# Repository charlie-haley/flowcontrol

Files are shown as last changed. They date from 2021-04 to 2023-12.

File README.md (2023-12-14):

> **Due to not having to the time to work on this, this project will be archived. It may return in another form in the future.**
>
<p align="center" style="text-align: center">
   <a href="https://flowctl.app">
      <br/>
   </a>
   An open source, multiplatform fan controller.
</p>

**This project is still in a very early state. If you'd like to contribute, [please take a look at our outstanding issues](https://github.com/charlie-haley/flowcontrol/issues) and raise a PR** 
Alternatively, head over to [discussions](https://github.com/charlie-haley/flowcontrol/discussions) if you have any questions or ideas.




<p align="center" style="text-align: center">
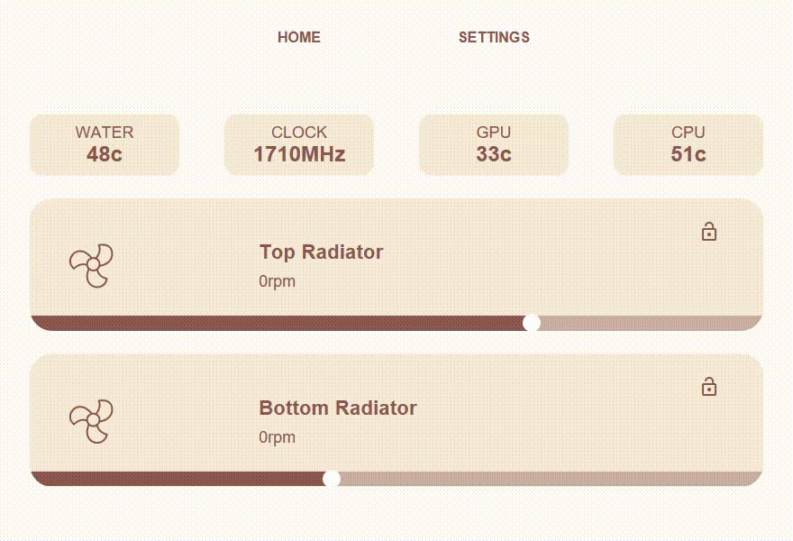
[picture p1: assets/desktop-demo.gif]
   <br/>
</p>

## 📝 Getting Started

[Head over to the documentation to get started.](https://flowctl.app/getting-started/requirements/)

## ❓ FAQ

- **What is this?**<br/>
A fan controller with open-source hardware, software and a CLI.

- **Who's it for?**<br/>
It's primarily aimed at desktop computer users, but it can fit many use cases.

- **How can I use flowcontrol?**<br/>
At the moment, you will need the ability to solder so you can build the hardware, if it proves popular I may release some pre-built controllers. [You can find the documentation on building the controller here.](https://flowctl.app/getting-started/requirements/)

- **Why would I use this over X?**<br/>
This started out as a project for me to use personally, I was tired of expensive fan controllers with proprietary connectors and no Linux support.

## Special Thanks

Huge thank you to all the awesome open source projects that have made this possible!
- [Wails](https://github.com/wailsapp/wails)
- [Cobra](https://github.com/spf13/cobra)
- [Raspberry Pi Pico](https://www.raspberrypi.org/products/raspberry-pi-pico/)
- [YoungSerif](https://github.com/noirblancrouge/YoungSerif)
- [KiCad](https://www.kicad.org/)
- [Gridsome](https://github.com/gridsome/gridsome)

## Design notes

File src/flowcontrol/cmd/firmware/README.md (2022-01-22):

# firmware

The firmware has been written around a [rp2040 microcontroller](https://www.raspberrypi.org/documentation/rp2040/getting-started/), prototypes have been built using the [Raspberry Pi Pico](https://www.raspberrypi.org/products/raspberry-pi-pico/)

## Compiling with tinygo
```
tinygo build -o=$(pwd)/main.uf2 -target=pico main.go
```

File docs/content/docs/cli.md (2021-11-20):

---
description: ''
sidebar: 'docs'
---

## CLI
A CLI application built using [cobra](https://github.com/spf13/cobra)

## Prerequisites
- Go 1.12+

## Running Locally
```
cd src/flowcontrol-cli/
go install flowctl
```

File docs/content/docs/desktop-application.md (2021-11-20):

---
description: ''
sidebar: 'docs'
---

## Desktop Application
This is the GUI application. It's built using [wails](https://wails.app/)

## Prerequisites
- Go 1.12+
- npm
- net5 SDK (Optional, only required if you're using the monitor)

### Linux
- gcc, gtk, webkitgtk

## Running locally

### flowcontrol
```
cd src/flowcontrol/
wails serve

cd src/flowcontrol/frontend
npm run serve
```

### flowcontrol-monitor
This is the supplementary application to the main one. It provides system metrics such as GPU Clock and temperatures using [LibreHardwareMonitorLib](https://github.com/LibreHardwareMonitor/LibreHardwareMonitor). I'm aiming to make this an optional component for people who want hardware metrics beyond the scope of the controller, it's currently bundled with the release.
```
cd src/flowcontrol-monitor/
dotnet run
```

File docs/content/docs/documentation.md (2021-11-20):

---
description: ''
sidebar: 'docs'
---

## Documentation
## Prerequisites

- Gridsome CLI

## Running Locally
```
cd src/flowcontrol/docs
gridsome develop
```

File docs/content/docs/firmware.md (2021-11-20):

---
description: ''
sidebar: 'docs'
---

## Firmware

## Prerequisites

- Micro USB Cable

Flash firmware to the RPI Pico using your favourite IDE (VSCode, Thonny)

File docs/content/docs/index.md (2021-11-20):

---
description: ''
sidebar: 'docs'
next: '/docs/pcb/'
---

# Introduction

Existing consumer fan controllers can be expensive, contain properietry connectors and the software that ships with them is usually incompatible with any operating system aside from Windows.

The aim of this project is make an accessible and extensible fan controller that is built for the user.

## Features
- Cheap, open source hardware built on top of the readily available Raspberry Pi Pico
- Lightweight desktop app
- Command line interface
- Support for external temp sensors
- User configurable fan curves (coming soon!)
- DRGB strip support (coming soon!)

## Parts List
__!! Note: If you can solder SMD components, there's a PCB available. [Please refer to the PCB documentation for the relevant parts list](/docs/pcb). !!__

Here's a list of parts you'll need if you'd like to build the hardware yourself:

- USB to UART module
- [Raspberry Pi Pico](https://www.raspberrypi.org/products/raspberry-pi-pico/)
- x2 Female and Male JST Connectors (For temp sensors, optional)
- 1 of each, per fan:
  - 4-Pin PWM Fan Connector Male
  - 10k Resistors

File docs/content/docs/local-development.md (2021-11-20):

---
description: ''
sidebar: 'docs'
---

# Local Development

The code base consists:

  - [flowcontrol](#desktop-application)
  - [flowcontrol-monitor](#desktop-application)
  - [flowcontrol-cli](#cli)
  - [firmware](#firmware)
  - [documentation](#documentation)

`flowcontrol` and `flowcontrol-cli` are currently independent, I'm looking to consolidate their codebase now they're both using Go and utilise shared packages for stuff like serial communication.

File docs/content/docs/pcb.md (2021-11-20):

---
description: ''
sidebar: 'docs'
prev: '/docs/'
next: '/docs/writing-content/'
---

# PCB

## Layout



## Bill Of Materials

Here's a list of parts with the corresponding designator on the PCB and the footprint.

| Designator | Comment | Footprint |
|:---:|:---:|:---:|
| C1 | 10uF | C_0603_1608Metric |
| C2, C3, C6 | 100nF | C_0603_1608Metric |
| C4, C5 | 22pF | C_0603_1608Metric |
| D1, D2 | LL4148 | D_SMA |
| D3, D4, D5 | LED | D_SMA |
| R1, R2, R3, R4  | 10k Ω | R_0603_1608Metric |
| R5, R6, R7, R8  | 1k5 | R_0603_1608Metric |
| SW1 | K2-1102SP-C4SC-04 | SW_Push_1P1T_NO_6x6mm_H9.5mm |
| U1 | 12MHz Crystal | RPI Pico |
| U2 | CH340G | SOIC-16_3.9x9.9mm_P1.27mm |
| Y1 | 12MHz Crystal | Crystal_SMD_HC49-SD |
| J1, J2 | 4 Pin PWM Fan Connector | Right Angle |
| J3, J4 | 2 Pin JST XH | 2 Pin JST XH |
| J5 | 2x05 2.54mm Female Header  | 2x05 2.54mm Female Header |
| J6 | MATE-N-LOK 350211-1 | (4 Pin "Molex" Connector) |
| J7 | 1x04 2.54mm Male Header | 1x04 2.54mm Male Header |

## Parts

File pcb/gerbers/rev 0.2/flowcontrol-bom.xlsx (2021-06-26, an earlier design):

Comment | Designator | Footprint | LCSC Part #（optional）
10uF | C1 | C_0603_1608Metric
100nF | C2 | C_0603_1608Metric
100nF | C3 | C_0603_1608Metric
22pF | C4 | C_0603_1608Metric
22pF | C5 | C_0603_1608Metric
100nF | C6 | C_0603_1608Metric
LL4148 | D1 | D_SMA
LL4148 | D2 | D_SMA
LED | D3 | D_SMA
LED | D4 | D_SMA
LED | D5 | D_SMA
10k Ω | R1 | R_0603_1608Metric
10k Ω | R2 | R_0603_1608Metric
10k Ω | R3 | R_0603_1608Metric
10k Ω | R4 | R_0603_1608Metric
1k5 | R5 | R_0603_1608Metric
1k5 | R6 | R_0603_1608Metric
1k5 | R7 | R_0603_1608Metric
1k5 | R8 | R_0603_1608Metric
K2-1102SP-C4SC-04 | SW1 | SW_Push_1P1T_NO_6x6mm_H9.5mm
CH340G | U2 | SOIC-16_3.9x9.9mm_P1.27mm
12MHz Crystal | Y1 | Crystal_SMD_HC49-SD

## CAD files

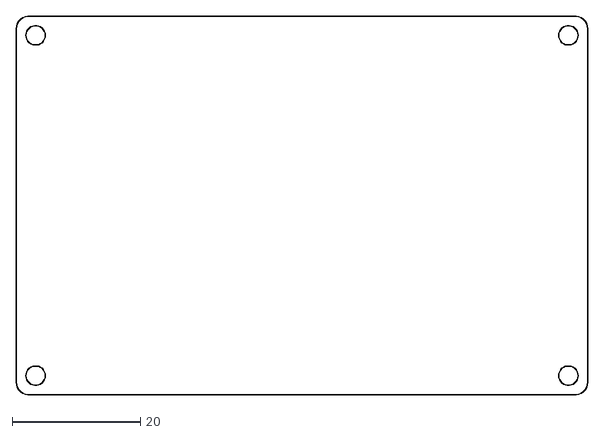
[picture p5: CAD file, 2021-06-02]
pcb/src/outline.dxf
89.0 x 59.0

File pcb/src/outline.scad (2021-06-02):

difference(){  
    minkowski()
    {
        square([85, 55], center = true);
        circle(r=2, $fn=30);
    }
    translate([41.5,26.5]) circle(d=3.01, $fn=30);
    translate([-41.5,26.5]) circle(d=3.01, $fn=30);
    translate([41.5,-26.5]) circle(d=3.01, $fn=30);
    translate([-41.5,-26.5]) circle(d=3.01, $fn=30);
}

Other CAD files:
assets/flowcontrol-logo.dxf

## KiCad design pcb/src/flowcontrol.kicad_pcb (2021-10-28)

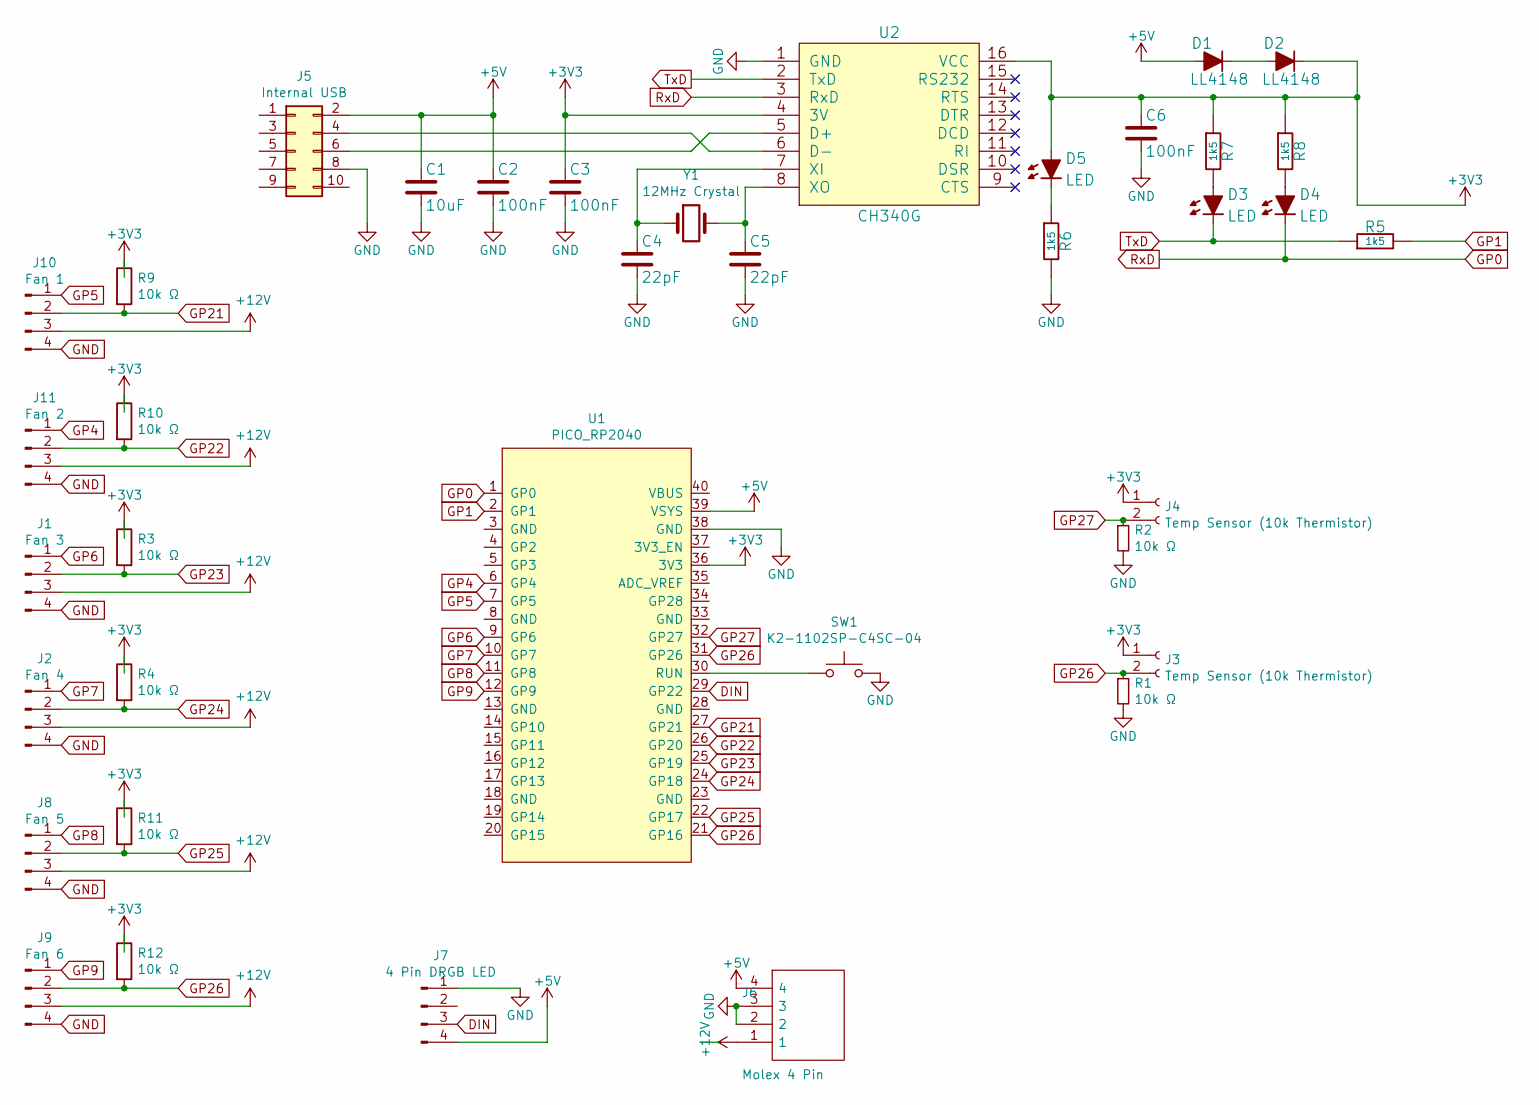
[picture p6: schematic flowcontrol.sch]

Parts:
C1: 10uF; C_0603_1608Metric
C2, C3, C6: 100nF; C_0603_1608Metric
C4, C5: 22pF; C_0603_1608Metric
D1, D2: LL4148; D_SMA
D3, D4, D5: LED; D_SMA
J1: Fan 3; PinHeader_1x04_P2.54mm_Horizontal
J2: Fan 4; PinHeader_1x04_P2.54mm_Horizontal
J3, J4: Temp Sensor (10k Thermistor); JST_XH_S2B-XH-A-1_1x02_P2.50mm_Horizontal
J5: Internal USB; PinSocket_2x05_P2.54mm_Horizontal
J6: Molex 4 Pin; 641737-1
J7: 4 Pin DRGB LED; PinHeader_1x04_P2.54mm_Horizontal
J8: Fan 5; PinHeader_1x04_P2.54mm_Horizontal
J9: Fan 6; PinHeader_1x04_P2.54mm_Horizontal
J10: Fan 1; PinHeader_1x04_P2.54mm_Horizontal
J11: Fan 2; PinHeader_1x04_P2.54mm_Horizontal
R1, R2, R3, R4, R9, R10, R11, R12: 10k Ω; R_0603_1608Metric
R5, R6, R7, R8: 1k5; R_0603_1608Metric
SW1: K2-1102SP-C4SC-04; SW_Push_1P1T_NO_6x6mm_H9.5mm
U1: PICO_RP2040; RPi_Pico_SMD_TH
U2: CH340G; SOIC-16_3.9x9.9mm_P1.27mm
Y1: 12MHz Crystal; Crystal_SMD_HC49-SD

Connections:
+3V3: C3.1, C6.1, D2.1 (A), D5.2 (C), J3.1, J4.1, R3.1, R4.1, R7.1, R8.1, R9.1, R10.1, R11.1, R12.1, U1.36 (3V3), U2.4 (3V), U2.16 (VCC)
+5V: C1.1, C2.1, D1.2 (C), J5.2, J6.4, J7.4, U1.39 (VSYS)
+12V: J1.3, J2.3, J6.1, J8.3, J9.3, J10.3, J11.3
DIN: J7.3, U1.29 (GP22)
GND: C1.2, C2.2, C3.2, C4.2, C5.2, C6.2, J1.4, J2.4, J5.8, J6.2, J6.3, J7.1, J8.4, J9.4, J10.4, J11.4, R1.2, R2.2, R6.2, SW1.2, U1.38 (GND), U2.1 (GND)
GP0: D4.1 (A), U1.1 (GP0), U2.3 (RxD)
GP1: R5.2, U1.2 (GP1)
GP4: J11.1, U1.6 (GP4)
GP5: J10.1, U1.7 (GP5)
GP6: J1.1, U1.9 (GP6)
GP7: J2.1, U1.10 (GP7)
GP8: J8.1, U1.11 (GP8)
GP9: J9.1, U1.12 (GP9)
GP21: J10.2, R9.2, U1.27 (GP21)
GP22: J11.2, R10.2, U1.26 (GP20)
GP23: J1.2, R3.2, U1.25 (GP19)
GP24: J2.2, R4.2, U1.24 (GP18)
GP25: J8.2, R11.2, U1.22 (GP17)
GP26: J3.2, J9.2, R1.1, R12.2, U1.21 (GP16), U1.31 (GP26)
GP27: J4.2, R2.1, U1.32 (GP27)
unnamed: C4.1, U2.7 (XI), Y1.1
unnamed: C5.1, U2.8 (XO), Y1.2
unnamed: D1.1 (A), D2.2 (C)
unnamed: D3.2 (C), R7.2
unnamed: D4.2 (C), R8.2
unnamed: D5.1 (A), R6.1
unnamed: J5.4, U2.6 (D-)
unnamed: J5.6, U2.5 (D+)
unnamed: SW1.1, U1.30 (RUN)
TxD: D3.1 (A), R5.1, U2.2 (TxD)

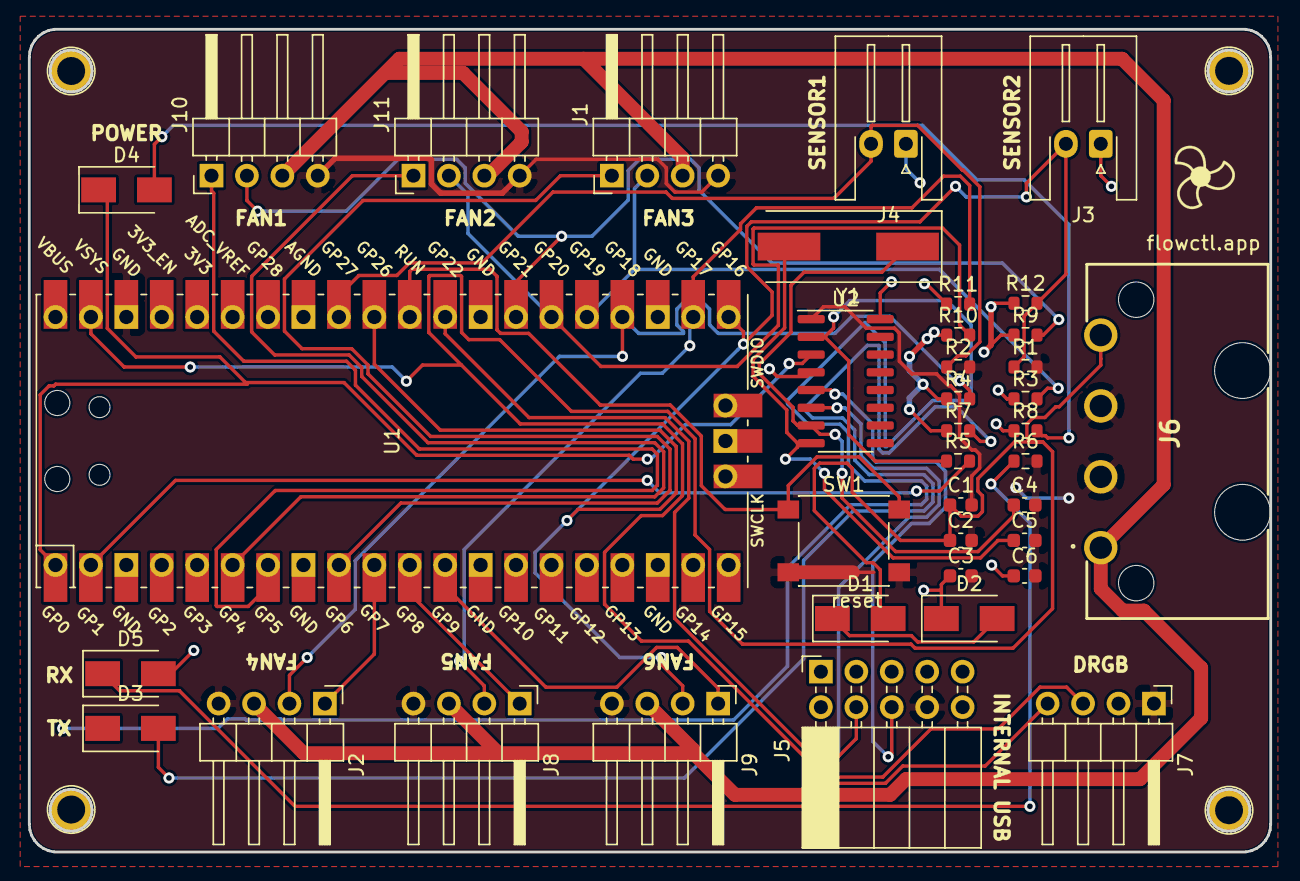
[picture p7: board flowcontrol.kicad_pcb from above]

Board: 2 copper layers, 89.0 x 59.0 mm, 38 parts (0 on the bottom side), 30 nets.

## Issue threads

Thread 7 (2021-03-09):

Add Neopixels LED support

charlie-haley, 2021-03-09:
add support for Neopixels DRGB

charlie-haley, 2021-04-11:
resolved by https://github.com/charlie-haley/flowcontrol/pull/18

Closed 2021-04-11.

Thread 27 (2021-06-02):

PCB Improvements

charlie-haley, 2021-06-02:
- [x] - Fix orientation of right angle fan headers (current solution is use to vertical mounting ones and follow schematic for pin placement)
- [x] - Add reset button so the Pico can be reset without removing the molex
- [x] - Design CH340g circuit and have it presoldered on the PCB as an alternative to using a USB-TTY dongle
- [x] Thicker traces to avoid damaging the PCB as easily

charlie-haley, 2021-06-26:
PCB in production, files in #39

Closed 2021-06-26.

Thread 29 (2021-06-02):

2 clicks needed to register an event

charlie-haley, 2021-06-02:
ex. changing the fans auto state using the padlock symbol involves 2 clicks

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

the pico registers the following inputs
```
Received Input:XA0
Received Input:XA0
Received Input:XA1
Received Input:XA1
```

charlie-haley, 2021-06-02:
After a bit more investigation - it seems to be sending the previous serial input, it's pretty inconsistent.

charlie-haley, 2021-06-02:
serial console and CLI app exhibinting similar behaviour, issue possibly on firmware side of things

charlie-haley, 2021-08-23:
Unable to replicate this on the latest revision PCB + Firmware. Closing

Closed 2021-08-23.

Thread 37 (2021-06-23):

Serial IO randomly breaks

charlie-haley, 2021-06-23:
Investigate why serial IO stops working.

I've tried replacing the CH340g for a rs232, issue looks to be on the pico/micropython side of things

charlie-haley, 2021-11-28:
Haven't seen this issue since the latest hardware revisions - closing for now.

Closed 2021-11-28.

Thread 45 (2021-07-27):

TX/RX Issues with rev 2 PCB

charlie-haley, 2021-07-27:
Issues with reading writing over UART on the new PCB. CH340 is detected and the TX LED lights up when sending data down the serial port

charlie-haley, 2021-08-08:
Issue was due to TX/RX being the wrong way around in the schematic. This will be fixed in the rev 3 PCB

Closed 2021-08-08.

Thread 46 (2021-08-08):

"Molex" 4 Pin Connector wrong way around

charlie-haley, 2021-08-08:
Fixed in rev3 PCB, tracking here

Closed 2021-08-08.

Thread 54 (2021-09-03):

Assign friendly device identifier

charlie-haley, 2021-09-03:
Investigate if I can assign a friendly name to the USB device - instead of showing as "CH340G" show "Flowcontrol" as the device identifier

charlie-haley, 2022-01-10:
the CH341A and CH340B have onboard EEPROM, it may be possible to use one of those, it'll also make this https://github.com/charlie-haley/flowcontrol/issues/5 infinitely simpler (potential rev 5 PCB task)

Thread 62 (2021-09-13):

Move firmware to TinyGo

charlie-haley, 2021-09-13:
Currently can't move the firmware to TinyGo due to the rp2040 not having PWM support, this is being worked on. See: https://github.com/tinygo-org/tinygo/issues/1993

charlie-haley, 2021-10-01:
Now being worked on

Closed 2022-01-22.

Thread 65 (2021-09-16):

Create revision 4 PCB

charlie-haley, 2021-09-16:
- [x] Use 3.3v pull-up instead of 5v on the tach
- [x] Increase fan headers to 6 with 6 independent PWM channels
- [ ] Potentially add generic power connector so SATA or "Molex" 4-Pin can be used
- [x] Add right angle internal USB connector

charlie-haley, 2021-11-12:
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

final layout of PCB, sent off for fab.

Closed 2021-11-12.

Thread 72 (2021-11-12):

build gerber files as part of the pipeline

charlie-haley, 2021-11-12:
investigate if gerber files can be built as part of the pipeline

charlie-haley, 2021-12-11:
This should be possible with Python bindings shipped with Kicad https://github.com/KiCad/kicad-source-mirror/blob/master/demos/python_scripts_examples/gen_gerber_and_drill_files_board.py

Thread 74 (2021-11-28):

sensor 2 outputs similiar reading to sensor 1

charlie-haley, 2021-11-28:
Sensor 2 is outputting a similar reading to sensor 1, it also looks like when only 1 sensor is connected the reading is double what it should it be.

Needs further investigation.

_Note: I haven't had the chance to try different thermistors, so the double reading could be an issue there._

charlie-haley, 2021-12-10:
Tested with new thermistors, issue lies with the thermistor, not the firmware/hardware. Closing.

charlie-haley, 2021-12-10:
I was wrong, issue seems to still be present - it's also registering a value in sensor 2 with nothing connected, I'm leaning towards hardware issue

charlie-haley, 2022-01-10:
factoring in the resistance of both sensors when fetching the rth seems to work for now, will investigate further and re-open if it should be solved in the hardware

charlie-haley, 2022-01-22:
re-opening, the sensor reading is now accurate but, value is identical

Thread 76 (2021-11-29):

LEDS not functioning as expected on the PCB

charlie-haley, 2021-11-29:
LEDs are in the wrong positions on the rev 4 PCB

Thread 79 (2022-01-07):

investigate need for EEPROM

charlie-haley, 2022-01-07:
investigate need for EEPROM, or if the filesystem on the pico will suffice, should be possible with https://github.com/tinygo-org/tinyfs

things to test:
- [ ] persistence
- [ ] speed and reliability

charlie-haley, 2022-01-07:
after further investigation, I'm opting for EEPROM, will be added to the revision 5 PCB

Closed 2022-01-07.

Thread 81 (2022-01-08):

only echo state when there's a change

charlie-haley, 2022-01-08:
**What problem are you looking to solve**
Currently, the state echo has to be triggered on input over UART. Ideally a routine will run in the background, monitor the state of sensors and fans and echo a response only when they've been updated

**Additional context**
The desktop app polls the hardware to get a response to get around this, but it's not ideal

Closed 2022-01-22.

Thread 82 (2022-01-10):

firmware to detect connected fans

charlie-haley, 2022-01-10:
**What problem are you looking to solve**
The firmware will need to detect if a fan is connected, then report on it. This will most likely come with tach support as we can detect the RPM of the fan https://github.com/charlie-haley/flowcontrol/issues/6

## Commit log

2021-03-11 DNMY - Basic start to PCB/CLI updates (#11)
    * initial commit
    * initial commit
    * initial commit
    * modify port num to prevent clash with logitech
    * move to blazor, add hacky RGB support to nano
    * add missing files
    * tidy up messy firmware a bit
    * fix issue with auto mode
    * Add new firmware using rp2040
    * add cli, move folder structure
    * CLI in somewhat working state and firmware updates
    * Remove old firmware
    * add basic start to PCB/Cli updates
    * update PCB
    [flowcontrol-v0.1.kicad_pcb, flowcontrol-v0.1.sch]
2021-03-13 Improvements to Thermistor readings (#14)
    * improve handling of temp reading
    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
2021-04-04 Migrate away from Chromely, use Wails instead (#15)
    * Migrate away from Chromely, use Wails instead
    * add flowcontrol-monitor application
2021-04-06 Desktop app updates (#16)
    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
2021-05-09 Bump ssri from 6.0.1 to 6.0.2 in /src/flowcontrol/frontend (#21)
    Bumps [ssri](https://github.com/npm/ssri) from 6.0.1 to 6.0.2.
    - [Release notes](https://github.com/npm/ssri/releases)
    - [Changelog](https://github.com/npm/ssri/blob/v6.0.2/CHANGELOG.md)
    - [Commits](https://github.com/npm/ssri/compare/v6.0.1...v6.0.2)
2021-05-09 Bump hosted-git-info from 2.8.8 to 2.8.9 in /src/flowcontrol/frontend (#22)
    Bumps [hosted-git-info](https://github.com/npm/hosted-git-info) from 2.8.8 to 2.8.9.
    - [Release notes](https://github.com/npm/hosted-git-info/releases)
    - [Changelog](https://github.com/npm/hosted-git-info/blob/v2.8.9/CHANGELOG.md)
    - [Commits](https://github.com/npm/hosted-git-info/compare/v2.8.8...v2.8.9)
2021-06-02 add v0.1 PCB files and gerbers (#28)
    * add v0.1 PCB files and gerbers
    * add v0.1 PCB files and gerbers
    [flowcontrol-v0.1-B_Cu.gbr, flowcontrol-v0.1-B_Mask.gbr, flowcontrol-v0.1-B_Paste.gbr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]
2021-06-09 Bump dns-packet from 1.3.1 to 1.3.4 in /src/flowcontrol/frontend (#30)
    Bumps [dns-packet](https://github.com/mafintosh/dns-packet) from 1.3.1 to 1.3.4.
    - [Release notes](https://github.com/mafintosh/dns-packet/releases)
    - [Changelog](https://github.com/mafintosh/dns-packet/blob/master/CHANGELOG.md)
    - [Commits](https://github.com/mafintosh/dns-packet/compare/v1.3.1...v1.3.4)
    ---
    updated-dependencies:
    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
2021-06-10 Bump ws from 6.2.1 to 6.2.2 in /src/flowcontrol/frontend (#35)
    Bumps [ws](https://github.com/websockets/ws) from 6.2.1 to 6.2.2.
    - [Release notes](https://github.com/websockets/ws/releases)
    - [Commits](https://github.com/websockets/ws/compare/6.2.1...6.2.2)
    - dependency-name: ws
    dependency-type: indirect
    ...
    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
2021-06-10 Bump browserslist from 4.16.3 to 4.16.6 in /src/flowcontrol/frontend (#36)
    Bumps [browserslist](https://github.com/browserslist/browserslist) from 4.16.3 to 4.16.6.
    - [Release notes](https://github.com/browserslist/browserslist/releases)
    - [Changelog](https://github.com/browserslist/browserslist/blob/main/CHANGELOG.md)
    - [Commits](https://github.com/browserslist/browserslist/compare/4.16.3...4.16.6)
    - dependency-name: browserslist
    ...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
2021-06-25 Bump postcss from 7.0.35 to 7.0.36 in /src/flowcontrol/frontend (#38)
    Bumps [postcss](https://github.com/postcss/postcss) from 7.0.35 to 7.0.36.
    - [Release notes](https://github.com/postcss/postcss/releases)
    - [Changelog](https://github.com/postcss/postcss/blob/main/CHANGELOG.md)
    - [Commits](https://github.com/postcss/postcss/compare/7.0.35...7.0.36)
    - dependency-name: postcss
    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
2021-06-26 v2 PCB + Website changes (#39)
    * add docs index
    * add docs index
    * add hugo docs
    * add hugo docs
    * update docs path
    * start new revision of PCB with integrated CH340G
    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
    [flowcontrol-B_Cu.gbr, flowcontrol-B_Mask.gbr, flowcontrol-B_Paste.gbr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]
2021-06-26 Create landing page for flowctl.app (#41)
    * improvements to website landing page
    * improvements to website landing page
2021-06-26 Add better mobile support for landing page on website (#42)
    * update logo and styling
    * better mobile support
    * better mobile support
    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
    [flowcontrol-logo.dxf]
2021-06-26 Update favicon and docs logo (#44)
    * update docs logo and favicon
    * update docs logo and favicon
    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
2021-08-08 add revision 3 PCB (#47)
    * add revision 3 PCB
    * remove test firmwares
    [flowcontrol-v0.1-B_Cu.gbr, flowcontrol-v0.1-B_Mask.gbr, flowcontrol-v0.1-B_Paste.gbr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]
2021-08-12 Bump path-parse from 1.0.6 to 1.0.7 in /src/flowcontrol/frontend (#50)
    Bumps [path-parse](https://github.com/jbgutierrez/path-parse) from 1.0.6 to 1.0.7.
    - [Release notes](https://github.com/jbgutierrez/path-parse/releases)
    - [Commits](https://github.com/jbgutierrez/path-parse/commits/v1.0.7)
    - dependency-name: path-parse
    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
2021-08-12 Bump tar from 6.1.0 to 6.1.8 in /src/flowcontrol/frontend (#49)
    Bumps [tar](https://github.com/npm/node-tar) from 6.1.0 to 6.1.8.
    - [Release notes](https://github.com/npm/node-tar/releases)
    - [Changelog](https://github.com/npm/node-tar/blob/main/CHANGELOG.md)
    - [Commits](https://github.com/npm/node-tar/compare/v6.1.0...v6.1.8)
    - dependency-name: tar
    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
2021-08-23 Update branding to follow new styling (#51)
    * add rev3 PCB layout to docs
    * Styling updates to follow new branding
    * Styling updates to follow new branding
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2021-10-28 Revision 4 PCB (#69)
    * rename kicad files
    * test signing key
    * create revision 4 PCB
    * add silkscreen for components
    * add gerbers
    [flowcontrol-B_Cu.gbr, flowcontrol-B_Mask.gbr, flowcontrol-B_Paste.gbr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]
2021-11-20 docs: documentation rework (#73)
    * docs: improve documentation/site
    * chore: update gitignore
    * fix: missing files
    * chore: update gitignore
    * fix: deployment
    * fix: ensure checks dont run for docs
    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
2022-01-22 fix: ensure sensors are updated (#84)
